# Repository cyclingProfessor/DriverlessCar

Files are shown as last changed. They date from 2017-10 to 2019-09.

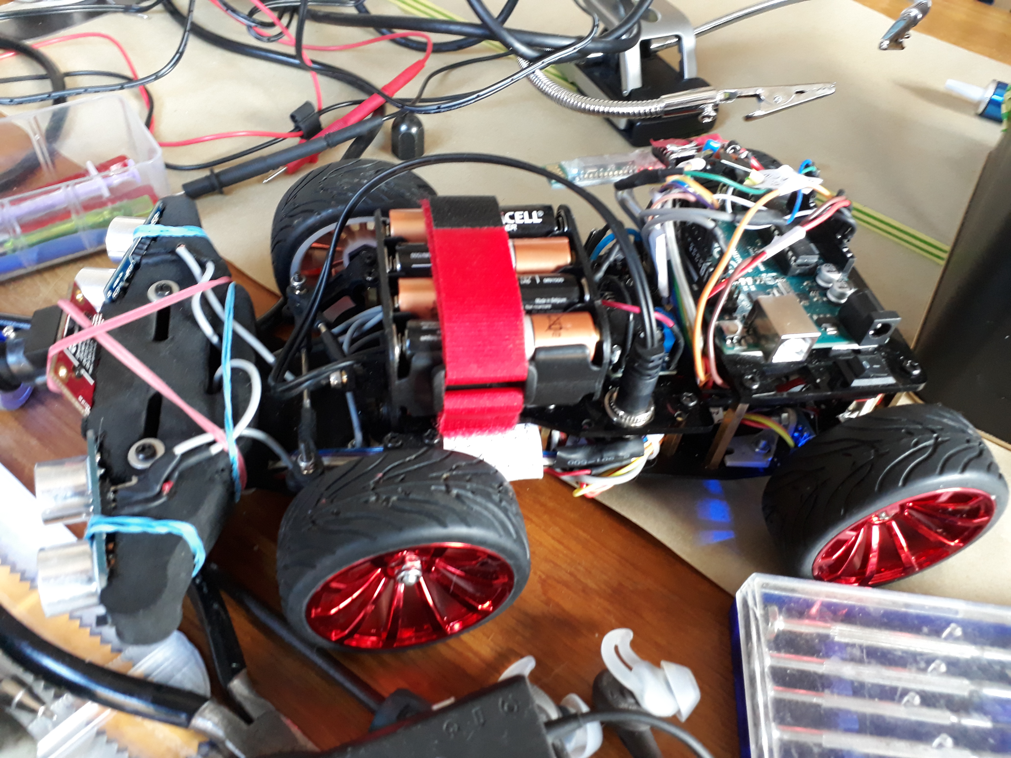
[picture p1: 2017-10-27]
Pictures/20171027_104041.jpg

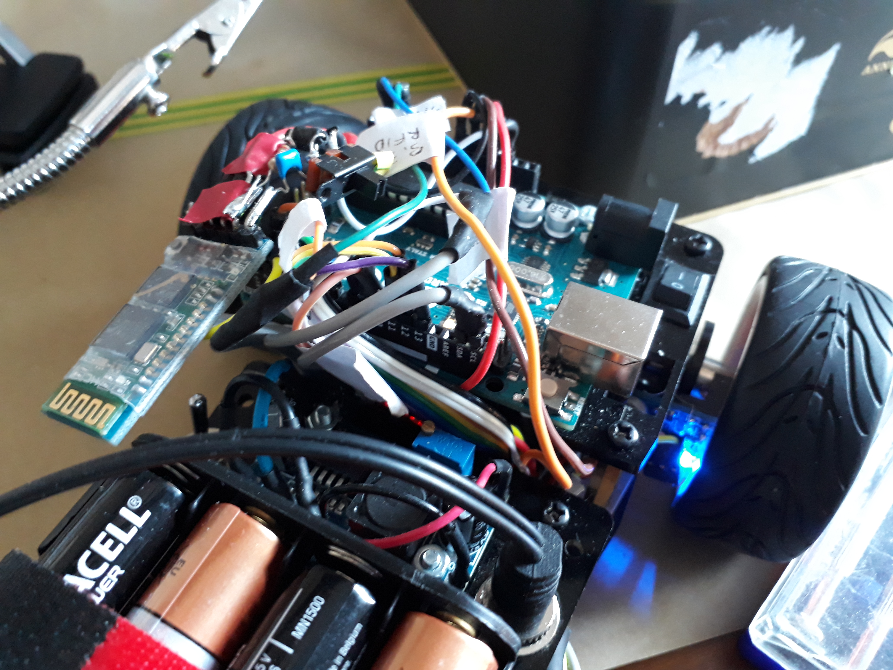
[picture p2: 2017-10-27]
Pictures/20171027_104059.jpg

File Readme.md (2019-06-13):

Complementary Infrastructure.
=============================
We live in a new age of automation, where the bins talk to the street lights and the buses converse with the traffic signals.
Sensors, tiny computers, powerful motors and effective batteries have all combined to make the impossible possible.  We expect that the autonomous car will take over from the driver and that it will not drive in the same way.  Why use vision alone when all other traffic is intelligent, and the roads, and the whole place, is intelligent?
This model has five computers: an Arduino, an RFID reader, a complex 3 axis multiple sensor and a mobile phone.  It has four power supplies.  It has 14 sensors.  It can run for three hours on one set of AA batteries.  It follows a magnetic stripe, watches for pedestrians, and responds to RFID tags.  It carefully monitors its own speed and position.  Using all these myriad signals it efficiently gets from place to place.
It is a miracle that demonstrates the integrated and complementary infrastructure.

====================================================

Now moved some common code into the CarLib library - so after cloning the git archive you will need to copy this into your arduino IDE library folder.

===================

Build System.
1. Must increase the Rx gain on the ANtenna to make RFID cards read fast enough.  This means adding one line to MFSC522 before PICC_..
2. Must change cpp flags to enable C++ 2011 standard to use SPI I2C library for MMU.
3. Must change SPI to SPI1 in the SDCard library so that it looks for the SDCard on the secondary SPI bus.

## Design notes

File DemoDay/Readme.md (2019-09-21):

Demo Day Software.
==================
Camera: SettableColors.py, State.py, CompressUtil.py
These are in the Camera/openMV folder
 State does all communications management
 CompressUtil uncompresses received images
 SettableColors can read images, switch between line following and calibration, and can process calibration messages.  It also sends periodic status updates.

Bluno: DemoDay.ino
  Initialises SD card, NFC reader, distances sensors, camera and Wemos.
  Does not yet use MMU.

Wemos D1 Lite:
  Processes speed and position from quad encoders on motor.
  Listens on either WiFi or Serial to commands: turn, speed, stop etc.,
  Stop from an obstruction knows whether the object is behind or in front so that it only stops when it is travelling towards the object.
  One command gets a status report.

===================

Build System.
1. Must increase the Rx gain on the ANtenna to make RFID cards read fast enough.  This means adding one line to MFSC522 before PICC_..
2. Must change cpp flags to enable C++ 2011 standard to use SPI I2C library for MMU.
3. Must change SPI to SPI1 in the SDCard library so that it looks for the SDCard on the secondary SPI bus.

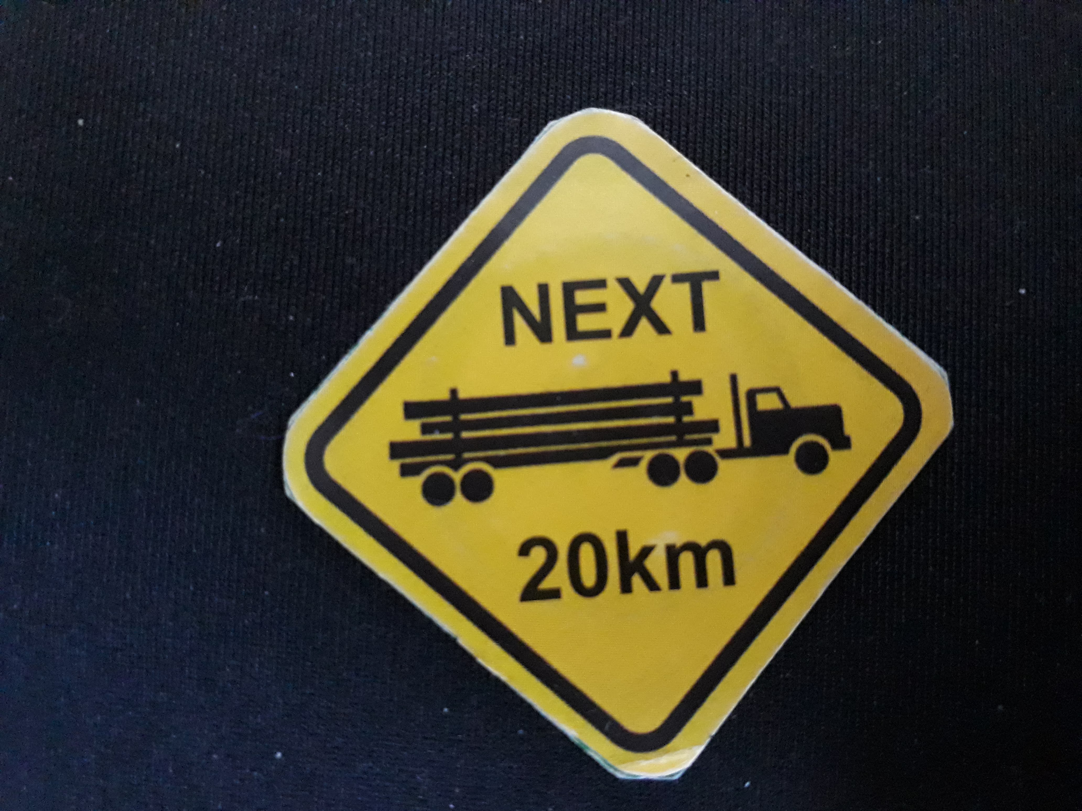
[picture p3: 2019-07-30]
Pictures/04EC8AFA904980.jpg

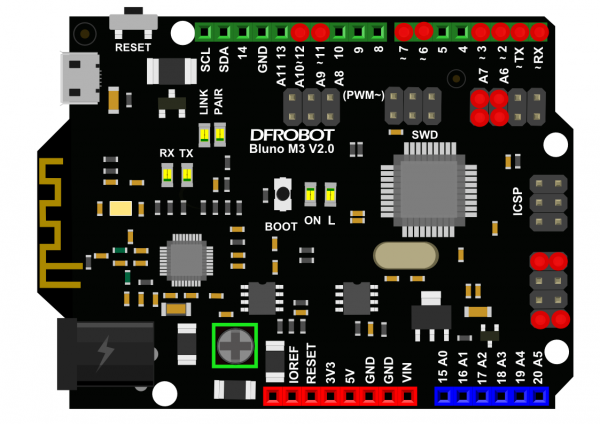
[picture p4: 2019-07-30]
Bluno M3/600px-PWM.png

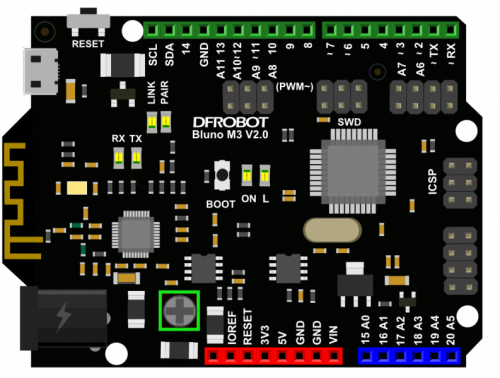
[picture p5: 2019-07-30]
Bluno M3/500px-Bluno_M3_Interrupt.png

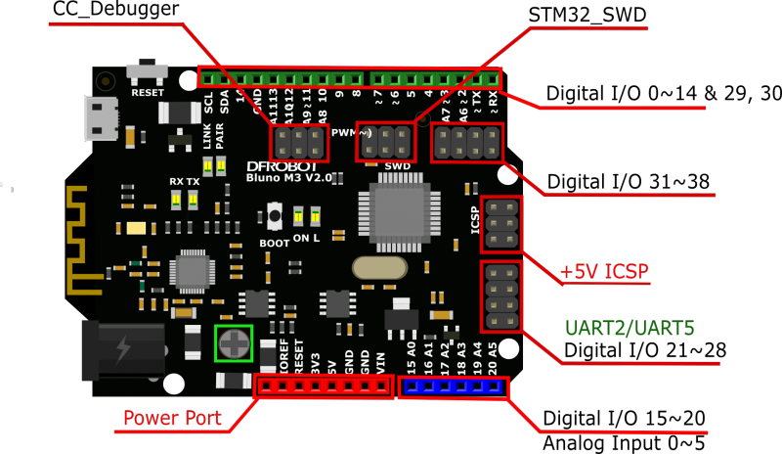
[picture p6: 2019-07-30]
Bluno M3/800px-DFR0329_M3GPIO.png

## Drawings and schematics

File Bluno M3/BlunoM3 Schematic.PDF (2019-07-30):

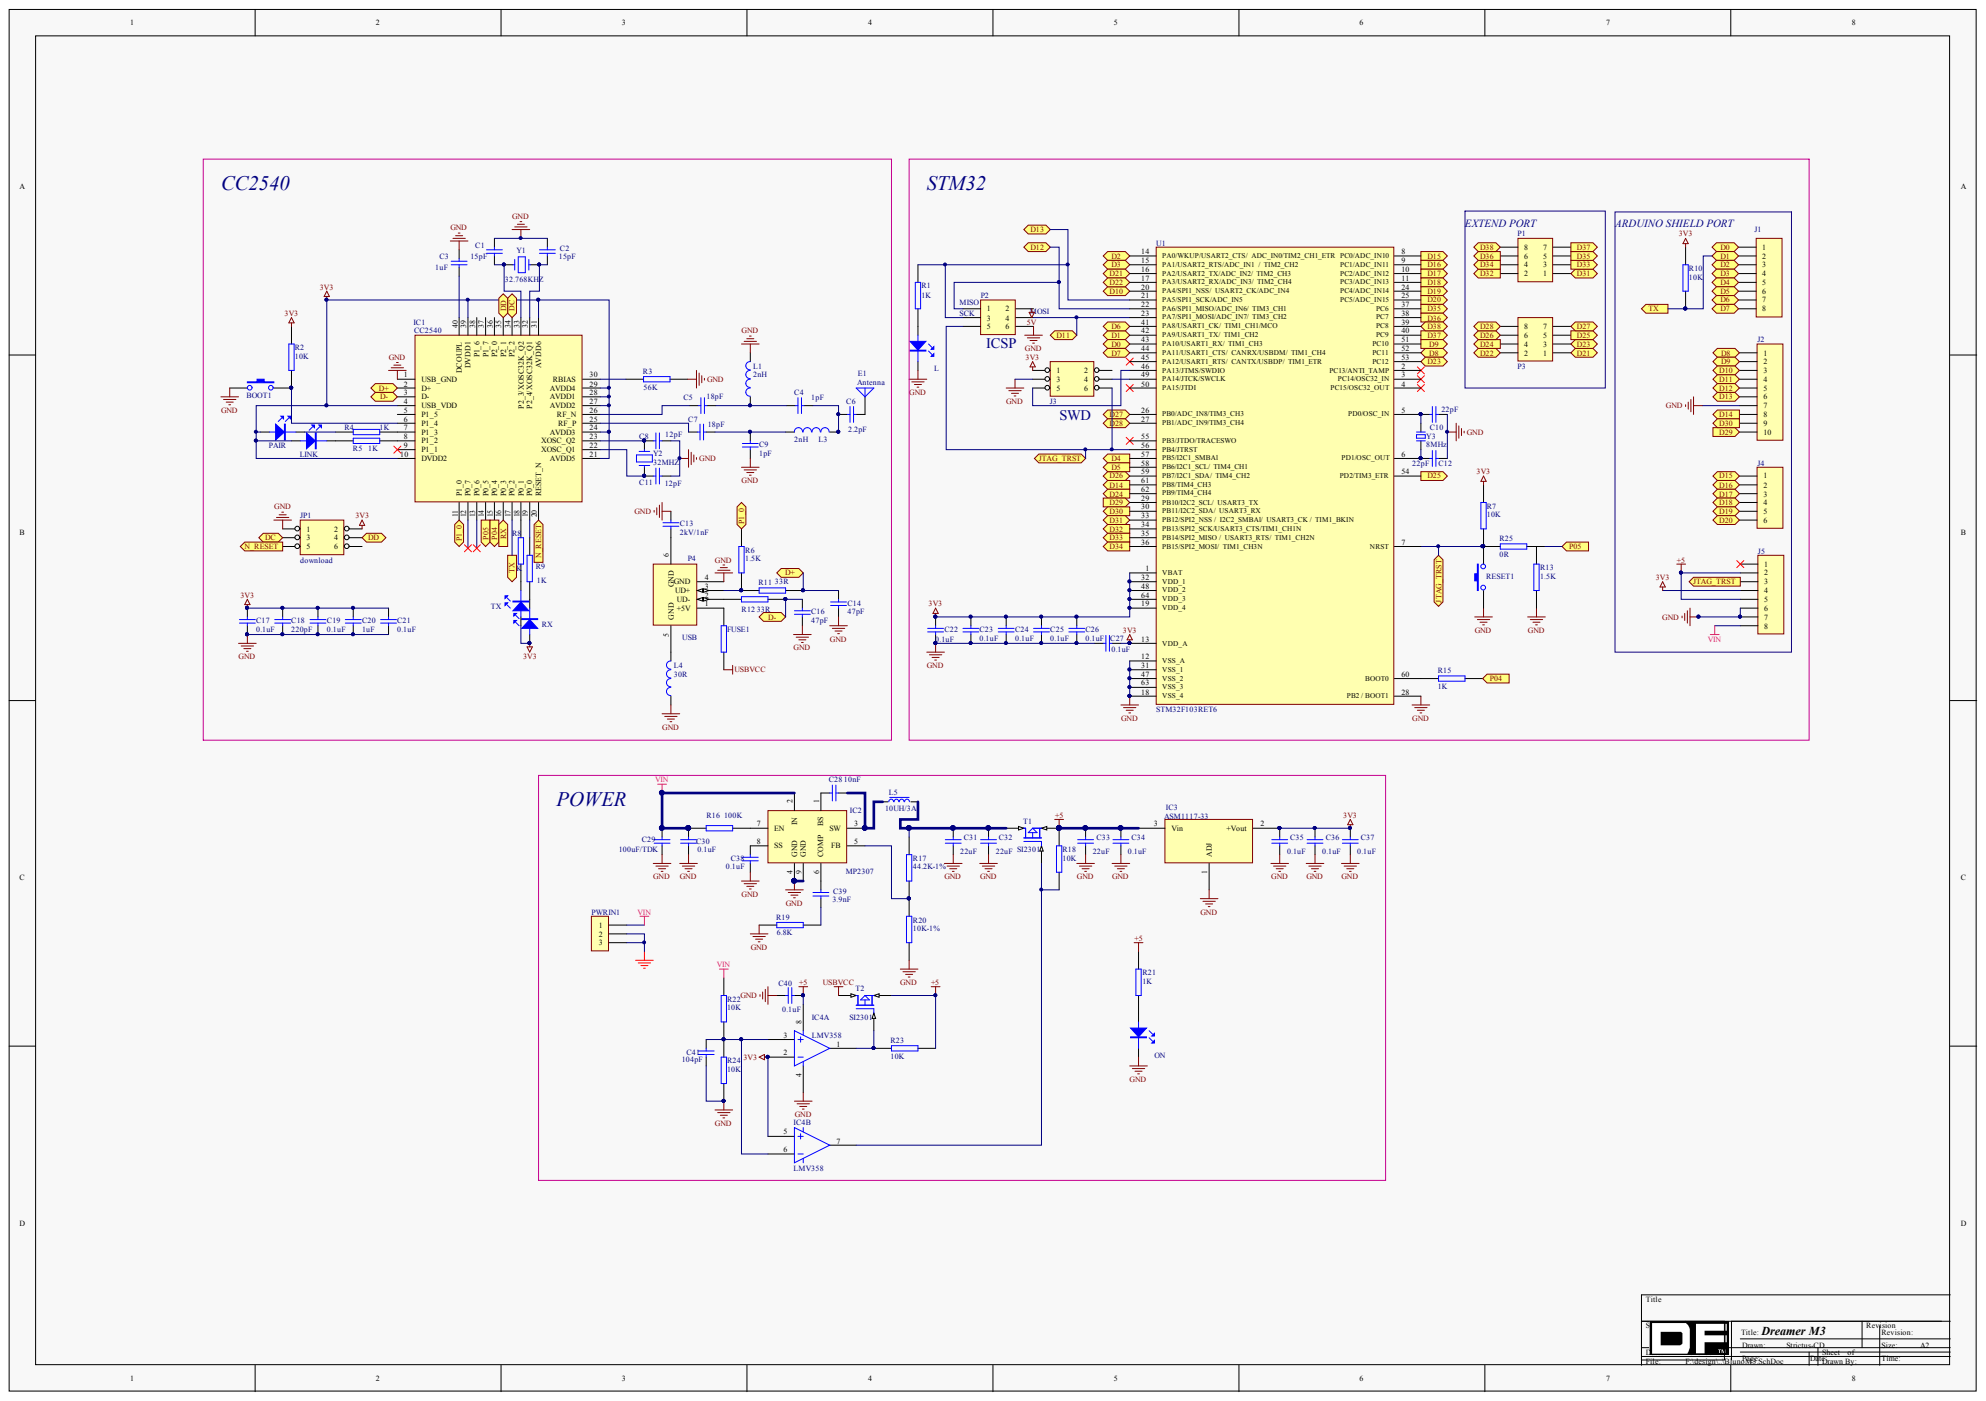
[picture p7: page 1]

3 4 5 6 | | PA14/JTCK/SWCLK 49

PB0/ADC_IN8/TIM3_CH3 26 | 3V3

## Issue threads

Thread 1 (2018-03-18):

No need to remove any I2C bytes from the buffer.

Koepel, 2018-03-18:
In the file "DriverlessCar/camera/Arduino/ReadAsMaster/ReadAsMaster.ino", the garbage bytes are tossed away when the amount of requested bytes was not received. That is not needed.

The Wire library uses packets of data (although it uses the Arduino Stream class).

Koepel, 2018-06-06:
Did something change ? I can not find it anymore. I think you used the word "garbage" in that file. Was it in another file, or is there a mix-up of Wire.avaible() and Serial.available() ? I was only talking about the I2C bus and the Wire library.

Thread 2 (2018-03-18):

Store the millis() value as a unsigned long, always use subtraction.

Koepel, 2018-03-18:
To avoid the rollover problem, the millis() value should be stored as a unsigned long and only a subtraction should be used to calculate the passed time. That subtraction must be done with two unsigned long variables.

See the Blink Without Delay example.

I spotted those problems in the next files. Sometimes the millis() value is stored in a long and sometimes the subtraction is missing. Comparing a value directly with millis() will go wrong with a rollover after about 50 days.

- "DriverlessCar/Sonar/Sonar.ino"
- "DriverlessCar/Polulo/reader/reader.ino"
- "DriverlessCar/lineFollow/Sensor.cpp"
- "DriverlessCar/lineFollow/Actions.cpp"
- "DriverlessCar/lineFollow/lineFollow.ino"
- "DriverlessCar/GyroMagnetAccel/GyroMagnetAccel.ino"

cyclingProfessor, 2018-06-06:
Thanks for this - however a battery driven toy is unlikely to last 50+ days :-)
Much of the logic for millis() has now changed.

Closed 2018-06-06.

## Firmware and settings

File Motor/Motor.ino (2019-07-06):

#include "Encoder.h"
#include "Ticker.h"
#include <ESP8266WiFi.h>
#include "Servo.h"

const char *Version = "Motor/Servo Controller V1.1"; 
const char *ssid = "ESPcarAP";
const char *password = "thisisnotaspoon";
int usingWiFi = false;

/***********************************************************************************************************\
* See https://docs.google.com/spreadsheets/d/1bhfsjG0d4l3q6j9Bx6Ja7MYPekk8pvvGrTb8yf0j5cc/edit?usp=sharing
* for details on ESP8266 pinout and its relationship to D1 Mini
\***********************************************************************************************************/

//WiFi Controls:
//
// + -Motor more forwards
// - -Motor more backwards
// 0 -Motor stop
// s - print stats
// L - Turn servo to Left
// R - Turn Servo to Right
// C - Centre servo
//
// Since this is run by the Wemos D1 Lite it can read from either Serial or from the Wifi

// UART protocol also has 'W' to toggle WiFi, '|n' and '~n' for direct speed and turn control.
char SPEED_CONTROL = '|';
char TURN_CONTROL = '~';

enum Command {
  NONE, HELP, WIFI, REPORT, TURN_LEFT, TURN_RIGHT, TURN_STRAIGHT, MOTOR_PLUS, MOTOR_MINUS, MOTOR_STOP, SET_SPEED, SET_TURN, BLOCK_BACK, BLOCK_FRONT
};

// Change to using Pololo TB6612FNG Mosfet controller

Command translate[128];
int commandArgument = 10;
/////////////////////////////////////// Pin Assignments /////////////////////////
int dir1Pin = D3; // => to TB6612FNG Pin INA1
int dir2Pin = D4; // => to TB6612FNG Pin INA2
int speedPin = D5; // => to TB6612FNG Pin PWMA (Needs to be a PWM pin to be able to control motor speed)
int steerPin = D6; // => Servo Control Wire (Orange) (Needs to be a PWM pin to be able to control servo angle)
int servoMotorPower = D8; // => Mosfet Board Signal, TB6612FNG STDY (Needs to start LOW (which is very rare on ESP8266))
int quadPinYellow = D1; // Needs Interupt
int quadPinGreen = D2; // Needs Interupt

///////////////////////////// Tunable constants /////////////////////////////////
#define SPEED_STEP 10
int desiredSpeed = 0;

const int NEUTRAL_ANGLE = 90;
int angle = NEUTRAL_ANGLE;

/////////////////// Hardware considerations ////////////////////////////
const int MAX_SERVO = 2000;
const int MIN_SERVO = 1000;
const int GLITCH = 40;  // How much to overturn to compensate for hysteresis
const int DELAY= 45; // How long to wait for a turn to complete.
unsigned long waitTime;
bool turnBack = false;

////////////////////// Speed and position calculations //////////////////
volatile int spCalcOfffset = 0;
volatile int speedEstimate[4]; // Average over 4 readings.
volatile int currentSpeed = 0;
volatile int lastPosition = 0;
volatile unsigned long lastTime = 0L;
int diffP = 0;
int diffT = 0;

//////////////////////////////// Objects ////////////////////////////
Encoder enc(quadPinYellow,quadPinGreen);
Ticker speedSetter;
WiFiServer server(3000);
WiFiClient client;
Servo   servo;

///////////////////////////////// CODE //////////////////////////////////////////
void setup() {  // Setup runs once per reset
  delay(1000);  // Wait for pins to settle.
  Serial.begin(115200);
  Serial.println(Version);
  pinMode(steerPin, OUTPUT);
  servo.attach(steerPin, MIN_SERVO, MAX_SERVO);
  servo.write(angle);
  delay(10);  // Wait for servo ctrl pin to settle.
  
  pinMode(servoMotorPower, OUTPUT);
  digitalWrite(servoMotorPower, HIGH);

  //Define TB6612FNG Dual H-Bridge Motor Controller Pins
  pinMode(dir1Pin, OUTPUT);  
  pinMode(dir2Pin, OUTPUT);
  pinMode(speedPin, OUTPUT);
  analogWrite(speedPin, 0);//Sets speed variable via PWM
  digitalWrite(dir1Pin, HIGH);
  digitalWrite(dir2Pin, HIGH);      
  
  speedSetter.attach_ms(10, setSpeed);
  for (int command = 0 ; command < 128 ; command++) {
    translate[command] = NONE;
  }
  translate['H'] = translate['?'] = HELP;
  translate['+'] = MOTOR_PLUS;
  translate['-'] = MOTOR_MINUS;
  translate['0'] = MOTOR_STOP;
  translate['s'] = REPORT;
  translate['L'] = TURN_LEFT;
  translate['R'] = TURN_RIGHT;
  translate['C'] = TURN_STRAIGHT;
}

void setSpeed() {
  static int counter = 0;
  static int motorPower = 0;
  static const int startPower = 300;
  
  unsigned long time = micros(); // Remember to check for overflow.
  int position = enc.read();
  if (time > lastTime) {
    // update speed estimate
    diffP = lastPosition - position;
    diffT = time - lastTime;
    // Circular buffer the speed estimate.
    
    // spCalcOfffset points to last entered speed - so remove this from total.
    currentSpeed -= speedEstimate[spCalcOfffset];
    
    // Put in new guess
    speedEstimate[spCalcOfffset] = (10000L * diffP) / diffT;
    currentSpeed += speedEstimate[spCalcOfffset];
    
    spCalcOfffset = (spCalcOfffset + 1) & 3;
  }
  lastTime = time;
  lastPosition = position;

  // Now set speed itself! Only every ten clicks
  counter ++;
  if (counter > 9) {
    counter = 0;
    if (desiredSpeed == 0) { // Stop is easy.
      analogWrite(speedPin, 0);//Sets speed variable via PWM
      digitalWrite(dir1Pin, HIGH);
      digitalWrite(dir2Pin, HIGH);
      return;      
    }
    if (currentSpeed > -5 && currentSpeed < 5) { // Overcome stopped friction.
        motorPower = startPower;
    }

    boolean forwards = (desiredSpeed >= 0);
    if (currentSpeed < desiredSpeed - 10) {
        motorPower += forwards ? 10 : -10 ;
    }
    if (currentSpeed > desiredSpeed + 10) {
        motorPower += forwards ? -10 : 10 ;
    }
    analogWrite(speedPin, motorPower);//Sets speed variable via PWM
    digitalWrite(dir1Pin, forwards ? HIGH : LOW);
    digitalWrite(dir2Pin, forwards ? LOW : HIGH);
  }
}

void toggleWiFi() {
  usingWiFi = ! usingWiFi;
  if (usingWiFi) {
    WiFi.softAP(ssid, password);
//      IPAddress myIP = WiFi.softAPIP();
    server.begin();
  } else {
    if (client) {
      client.stop();
    }
    server.stop();
    WiFi.softAPdisconnect(true); 
  }
}

Command getCommand() {
  if (usingWiFi) { // Is the WiFi server running?
    if (!client || !client.connected()) { // Does it NOT a current client?
      client = server.available(); // Get a WifFi client.
    }
    if (client) { // Do we have a current WiFi client?
      if (client.connected()) {
        if (client.available() > 0) {
          return(translate[client.read()]); // Return point here for reading a WiFi
        }
      } else { // Client has died - kill our WiFiClient object.
        client.stop();
      }
    }
  }

  // Here we have not managed to read from Wifi: try Serial protocol
  if (Serial.available()) {
    int next = Serial.read();
    if (translate[next] != NONE) {
      return translate[next];
    }
    // Protocol bytes are always not control bytes so cannot be misunderstood.  
    // They are '|' for speed and '~' for Turn, followed by an argument byte
    // Speed : take of ten from byte value, and multiply by ten.
    if (next == 'W') {
      return WIFI;
    }
    if (next == 'F') {
      return BLOCK_FRONT;
    }
    if (next == 'B') {
      return BLOCK_BACK;
    }
    // There will be another character - just wait here now.
    while (!Serial.available()) {
    }
    if (next == SPEED_CONTROL) {
      commandArgument = (Serial.read() - 10) * 10;
      return SET_SPEED;
    }
    if (next == TURN_CONTROL) {
      commandArgument = 10 * Serial.read();
      return SET_TURN;
    }
  }
  return NONE;  // Do nothing!
}

void report(Stream &out) {
  out.print("EstimatedSPeed: ");
  out.println(currentSpeed);
  out.print("Desired Speed: ");
  out.println(desiredSpeed);
  out.print("Turn Angle: ");
  out.println(angle); 
  out.print("WiFi: ");
  out.println(usingWiFi ? "ON" : "OFF");
  out.flush();
}

void help(Stream & out) {
  out.print(Version);
  out.print(HELP);
  out.flush();
}


void loop() {
  int turnTo;
  if (turnBack) {
    if (millis() > waitTime + DELAY) {
      turnBack = false;
      servo.write(angle);
    }
  }

  switch (getCommand()) {
    case WIFI: // Only UART - Toggle Wifi
      toggleWiFi();
      break;
    case HELP: // 'H' or '?'
      if (usingWiFi) help(client);
       help(Serial);
      break;
    case MOTOR_PLUS: // Only from Wifi - Motor 1 Forward
      desiredSpeed = min(desiredSpeed + SPEED_STEP, 90);
      break;
    case MOTOR_MINUS: // Only Wifi - Motor 1 Stop (Brake)
      desiredSpeed = max(desiredSpeed - SPEED_STEP, -60);
      break;
    case MOTOR_STOP: 
      desiredSpeed = 0;
      break;        
    case TURN_LEFT:
      // always arrive from the same direction (from a higher angle)
      angle -= 10;;
      servo.write(angle);
      break;
    case TURN_RIGHT:
      // always arrive from the same direction (from a higher angle)
      angle += 10;
      servo.write(angle+GLITCH);
      waitTime = millis();
      turnBack = true;
      break;
    case TURN_STRAIGHT:
      angle = NEUTRAL_ANGLE;
      servo.write(angle+GLITCH);
      waitTime = millis();
      turnBack = true;
      break;
    case REPORT:
      if (usingWiFi) report(client);
        report(Serial);
      break;
    case BLOCK_FRONT:
      // Blockage in front
      desiredSpeed = min(desiredSpeed, 0);
      break;
    case BLOCK_BACK:
      // Blockage behind
      desiredSpeed = max(desiredSpeed, 0);
      break;
    case SET_SPEED:
      desiredSpeed = max(min(commandArgument, 90), -60);
      break;
    case SET_TURN:
      turnTo = commandArgument;
      if (turnTo > angle) { // Turn Right
        // always arrive from the same direction (from a higher angle)
        turnTo += GLITCH;
        waitTime = millis();
        turnBack = true;
      } 
      servo.write(turnTo);
      angle = commandArgument;
      break;
    default:
      break;
  }
}

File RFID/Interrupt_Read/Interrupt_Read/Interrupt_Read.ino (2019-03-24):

#include <timerobj.h>
#include <SPI.h>
#include <MFRC522.h>

#define RST_PIN         9
#define SS_PIN          10
#define IRQ_PIN         8

HardwareSerial &Serial = Serial1;

MFRC522 mfrc522(SS_PIN, RST_PIN);
#define BLOCKS 16
byte buffer[2 * BLOCKS + 2];
#define VAL_OFFSET 6

volatile boolean bNewInt = false;
volatile boolean foundCard = false;
unsigned char regVal;

void readCard();
//Timer triggerTimer(50, readCard, t_period, NULL );

void setup() {
  Serial1.begin(115200); // Initialize serial communications with the PC
  while (!Serial1);    // Do nothing if no serial port is opened (added for Arduinos based on ATMEGA32U4)
  SPI.begin();        // Init SPI bus

  mfrc522.PCD_Init();

  /* setup the IRQ pin*/
  pinMode(IRQ_PIN, INPUT_PULLUP);

  /*
      Allow the ... irq to be propagated to the IRQ pin
      For test purposes propagate the IdleIrq and loAlert
  */
  mfrc522.PCD_WriteRegister(mfrc522.ComIEnReg, 0x20);
  mfrc522.PCD_WriteRegister(mfrc522.DivIEnReg, 0x90);

  /*Activate the interrupt*/
  attachInterrupt(IRQ_PIN, readCard, RISING);
  activateRec(mfrc522);
  delay(100);
  Serial1.println("End setup");
}

/**
   Main loop.
*/
void loop() {

  //readCard();
  if (bNewInt) { //new read interrupt
    bNewInt = false;
    Serial.print("Interrupt.");
    if (foundCard) {
      dump_byte_array(mfrc522.uid.uidByte, mfrc522.uid.size);
      Serial.print("<");
      Serial.print((char *)buffer + VAL_OFFSET);
      Serial.print(">");
    }
    Serial.println();
    foundCard = false;
  }

  Serial.println("Beginning to Wait for a Card.");
  delay(4000);
} //loop()

/**
   Helper routine to dump a byte array as hex values to Serial.
*/
void dump_byte_array(byte *buffer, byte bufferSize) {
  for (byte i = 0; i < bufferSize; i++) {
    Serial1.print(buffer[i] < 0x10 ? " 0" : " ");
    Serial1.print(buffer[i], HEX);
  }
}
/**
   MFRC522 interrupt serving routine
*/
void readCard() {
  bNewInt = true;
  clearInt(mfrc522);
  // Look for new cards
  if ( ! mfrc522.PICC_IsNewCardPresent())
    return;
  mfrc522.PICC_ReadCardSerial(); //read the tag data
  if (!readCardData())
    return;
  activateRec(mfrc522);
  foundCard = true;
}

/*
   The function sending to the MFRC522 the needed commands to activate the reception
*/
inline void activateRec(MFRC522 mfrc522) {
  mfrc522.PCD_WriteRegister(mfrc522.FIFODataReg, mfrc522.PICC_CMD_REQA);
  mfrc522.PCD_WriteRegister(mfrc522.CommandReg, mfrc522.PCD_Transceive);
  mfrc522.PCD_WriteRegister(mfrc522.BitFramingReg, 0x87);
}

/*
   The function to clear the pending interrupt bits after interrupt serving routine
*/
inline void clearInt(MFRC522 mfrc522) {
  mfrc522.PCD_WriteRegister(mfrc522.ComIrqReg, 0x7F);
}

boolean readCardData() {
  MFRC522::StatusCode status;
  byte size = BLOCKS + 2;

  byte blockAddr = 6;
  status = (MFRC522::StatusCode) mfrc522.MIFARE_Read(blockAddr, buffer, &size);
  if (status != MFRC522::STATUS_OK) {
    return false;
  }
  blockAddr = 10;
  status = (MFRC522::StatusCode) mfrc522.MIFARE_Read(blockAddr, buffer + 16, &size);
  if (status != MFRC522::STATUS_OK) {
    return false;
  }
  
  // second byte indicates length
  int length = buffer[1] - 3;  // Need to subtract 3 to get actual string length
  buffer[length + VAL_OFFSET] = 0;
  return true;
}

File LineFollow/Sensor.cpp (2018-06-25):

#include "LineFollow.h"

//////////////////////////////////////////////////////////////////////////////////////
CameraSensor::CameraSensor(int pin): controlPin(pin) {
    watching = false;
    pinMode(controlPin, OUTPUT);
    CameraSensor::calibrate();
}

void CameraSensor::watch() {
    digitalWrite(controlPin, HIGH);
    watching = true;
}
void CameraSensor::calibrate() {
  digitalWrite(controlPin, LOW);
  watching = false;
}

bool CameraSensor::isWatching() {
	return watching;
}

// This must not be called unless the camera is started
unsigned CameraSensor::getNormalisedValue() {
	if (!watching) {
		return 0; // This should never happen
	}
  byte value = MID_POINT;
  Wire.requestFrom(CAMERA_ADDR, 1);
  if (Wire.available()) {
    value = Wire.read();
  }
  return (value <= MAX_MESSAGE) ? value : MID_POINT ;
}

//////////////////////////////////////////////////////////////////////////////////////
void MagSensor::start() {
  while (!mag.init());
  mag.enableDefault();
  mag.writeReg(LIS3MDL::CTRL_REG2, 0x60);
}

unsigned MagSensor::getNormalisedValue() {
  return (abs(mag.m.x) + abs(mag.m.y) + abs(mag.m.z)) / 100u;
}

void MagSensor::update() {
    mag.read();
}

MFRC522 mfrc522(RFID_SS_PIN, RFID_RST_PIN);  // Create RFID reader instance

//////////////////////////////////////////////////////////////////////////////////////
void RFID::start() {
  SPI.begin();      // Init SPI bus
  mfrc522.PCD_Init();   // Init MFRC522
}

///////////////////////////////////////////////////////////////////////////////////////
// This utility function just reads and returns the text from a noticed RFID tag.
///////////////////////////////////////////////////////////////////////////////////////
const byte *RFID::readCardData() {
  const int VAL_OFFSET = 6;
  if (!mfrc522.PICC_IsNewCardPresent() || !mfrc522.PICC_ReadCardSerial()) {
    return NULL;
  }

  MFRC522::StatusCode status;
  byte size = BLOCKS + 2;

  byte blockAddr = 6;
  status = (MFRC522::StatusCode) mfrc522.MIFARE_Read(blockAddr, buffer, &size);
  if (status != MFRC522::STATUS_OK) {
    return NULL;
  }
  blockAddr = 10;
  status = (MFRC522::StatusCode) mfrc522.MIFARE_Read(blockAddr, buffer + 16, &size);
  if (status != MFRC522::STATUS_OK) {
    return NULL;
  }

  // Avoid seeing the same card twice!
  mfrc522.PICC_HaltA();

  // second byte indicates length
  int length = buffer[1] - 3;  // Need to subtract 3 to get actual string length
  buffer[length + VAL_OFFSET] = 0;
  return buffer + VAL_OFFSET;
}

//////////////////////////// Echo locator stuff ///////////////////////////////////////////////////////
NewPing sonar[2] = {
  NewPing(TRIGGER_PIN_LEFT, ECHO_PIN_LEFT, MAX_DISTANCE),
  NewPing(TRIGGER_PIN_RIGHT, ECHO_PIN_RIGHT, MAX_DISTANCE)
};

void EchoMonitor::start(int freq) {
  pinMode(TRIGGER_PIN_LEFT, OUTPUT);
  pinMode(ECHO_PIN_LEFT, INPUT);
  pinMode(TRIGGER_PIN_RIGHT, OUTPUT);
  pinMode(ECHO_PIN_RIGHT, INPUT);
  pingSpeed = freq;
  pingTimer = millis();
  echo_distances[0] = echo_distances[1] = NO_OBJECT;
}
void EchoMonitor::update() {
  long distance;
  if (millis() >= pingTimer) {   // pingSpeed milliseconds since last ping, do another ping.
    pingTimer += pingSpeed;      // Set the next ping time.
    distance = sonar[which_echo].ping_cm(MAX_DISTANCE);
    if (distance > 0) {
      echo_distances[which_echo] = distance; 
    } else {
      echo_distances[which_echo] = NO_OBJECT; 
    }
    which_echo = 1 - which_echo;
  }
}
unsigned int EchoMonitor::pingSpeed; // Frequency at which we ping
unsigned long EchoMonitor::pingTimer; // Holds the next ping time.
int EchoMonitor::which_echo = 0;  // which sonar to ping next

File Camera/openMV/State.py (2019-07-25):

import image, sensor
from CompressUtil import decompressImageStart, Uncompressor, DataStore

START = '{' # 123
END = '}' # 125
MSG_GOOD = 1
MSG_PARTIAL = 0
MSG_BAD = -1
MSG_NONE = -2

# A message
# START: CMD: Length: Data : End
# e.g 8: 'D': 3: '1': '2' : '3' : 10

class Message:
    def __init__(self):
        self.command = None
        self.dataBuffer = [None for i in range(20)]
        self.status = MSG_NONE # -2 for None yet, -1 for error, 0 for partial, 1 for complete
        self.dataCount = 0
        self.expected = -1
        self.picture = image.Image(50,44,sensor.RGB565)
        self.decompressTable = bytearray(3000)

######################################################################################

class State:
    """
    Define an interface for encapsulating the behavior associated with a
    particular state of the Context.
    """
    message = Message() # Single class variable
    def __init__(self):
        self._name = "None"
    def handleChar(self, rdr, recvd):
        #print('Error : NO STATE')
        pass

class StateImageReader(State):
    def __init__(self):
        super().__init__()
        self.started = False;
        self._name = "Image Reader"
        self.width = 0
    def handleChar(self, rdr, recvd):
        if ord(recvd) > 100:
            self.started = False;
            print(self._name + " - got Bad:" + str(recvd))
            self.message.status = MSG_BAD
            rdr._state = myStateWaiting
            return
        # The first two bytes are big endian 6-bit Data (compressed) counts.
        if not self.started:
            self.message.expected = ord(recvd)
            self.started = True
            return

        self.message.expected = 64 * self.message.expected + ord(recvd)
        self.message.dataCount = 0
        self.started = False

        print("Expecting : " + str(self.message.expected))
        if self.message.expected > 1000: # Size of decode table
            print(self._name + " - got Bad Image Size:" + str(self.message.expected))
            self.message.status = MSG_BAD
            rdr._state = myStateWaiting
            return
        rdr._state = myReadPixels
        myReadPixels.begin()

class StateReadPixels(State):
    def __init__(self):
        super().__init__()
        self._name = "Pixel Reader"
        self._buffer = bytearray(3)
        self._uc = None
        self._ds = None
        self.__escaped = False
    def begin(self):
        self.__escaped = False
    def handleChar(self, rdr, recvd):
        if recvd in [END, START]: # Only two bad characters! premature!
            print(self._name + " - got Bad:" + str(recvd))
            self.message.status = MSG_BAD
            rdr._state = myStateWaiting
            return
        val = ord(recvd)
        if self.__escaped:
            val += 10
            self.__escaped = False
        elif recvd == '|':
            # wait until next character
            self.message.dataCount += 1
            self.__escaped = True
            return

        if self.message.dataCount < 3: # build up initial buffer
            self._buffer[self.message.dataCount] = val
            if self.message.dataCount == 2:
                self._ds = DataStore(self._buffer, streamed = True)
                self._uc = decompressImageStart(self.message.picture, self.message.decompressTable, self._ds)
        else:
            self._ds.setStoreToByte(val)
            self._uc.uncompressBytes()

        self.message.dataCount += 1
        if self.message.dataCount == self.message.expected:
            rdr._state = myStateEnd

class StateWaiting(State):
    def __init__(self):
        super().__init__()
        self._name = "Waiting"
    def handleChar(self, rdr, recvd):
        # Simply ignore no-start characters.
        if recvd != START:
            print(self._name + " - Still Waiting - got:" + str(recvd))
            return
        self.message.status = MSG_PARTIAL
        rdr._state = myStateCMD

class StateCMD(State):
    def __init__(self):
        super().__init__()
        self._name = "CMD"
    def handleChar(self, rdr, recvd):
        if not recvd in ['C', 'R', 'L', 'P']: # Possible commands
            print(self._name + " - got Bad:" + str(recvd))
            self.message.status = MSG_BAD
            rdr._state = myStateWaiting
            return
        # Check CMD validity
        self.message.status = MSG_PARTIAL
        self.message.command = recvd
        self.message.dataCount = 0
        if recvd == 'P': # Picture command
            rdr._state = myImageReader
            print(self._name + " - got a picture command")
            return
        rdr._state = myStateCount

class StateCount(State): # count is offset from 64 ('@') - So 'A' == 1
    def __init__(self):
        super().__init__()
        self._name = "Count"
    def handleChar(self, rdr, recvd):
        count = ord(recvd) - ord('@')
        if count > 20:
            print(self._name + " - got Bad:" + str(recvd))
            self.message.status = MSG_BAD
            rdr._state = myStateWaiting
            return
        # Check Count validity (Certainly < 20)
        # If expected = 0 then straight to END
        self.message.expected = count
        self.message.dataCount = 0
        if self.message.expected == 0:
            rdr._state = myStateEnd
        else:
            rdr._state = myStateData

class StateData(State):
    def __init__(self):
        super().__init__()
        self._name = "Data"
    def handleChar(self, rdr, recvd):
        if recvd < '0' or recvd > '9':
            print(self._name + " - got Bad:" + str(recvd))
            rdr._state = myStateWaiting
            self.message.status = MSG_BAD
            return
        self.message.dataBuffer[self.message.dataCount] = recvd
        self.message.dataCount += 1
        if self.message.dataCount >= self.message.expected:
            rdr._state = myStateEnd

class StateEnd(State):
    def __init__(self):
        super().__init__()
        self._name = "End"
    def handleChar(self, rdr, recvd):
        if recvd != END:
            print(self._name + " - got Bad:" + str(recvd))
            self.message.status = MSG_BAD
        else:
            self.message.status = MSG_GOOD # Got a whole good self.message.
        rdr._state = myStateWaiting
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

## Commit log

2017-06-26 The various sketches test in isolation the various sensors on the car. LineFollow is the whole system put together
2017-10-18 1. Changed the pins that the echo sensors use from A4/A5 to A2/A3 since the A4/A5 pins are hard wired to the I2C SCL and SDA pin when I2c is started. This meant that the echo sensors interfered with 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
    2. Also created files to make the OpenMV camera report a green line position.
    This code searches for green blob of sufficient size at an appropriate distnace in front of the car. It is very susceptible to light conditions even though it uses LAB colour coding.
2017-10-27 Beginning to add support for the OpenMV camera with line following and slave I2c
2018-05-22 The CarServo program allows you to specify the angle (10-105 degrees) for the servo motor to see what effect that has on teh wheels, and to test for repeatability and hysteresis.
2018-05-22 iThis is the program - with the newly added digital line 6 - that allows the arduino to switch between follow and calibrate modes. it sends regular fixed format angles to the line at 20cm when in fol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
    [AutoTrack.py]
2018-05-22 This sketch can be used to see the communication from the car camera. It can switch the car to/from calibrate mode using serial entries. it seems reliable with either the sketch or the car starting f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
2018-05-23 The readme.h file in CarServo no longer reflectd its use. The slave code for the openMV camera is redundant and incorporated in better examples.
2018-05-24 This is a change to fix a couple of bugs in this tester program. Specivically it correct the switch statement so that we can switch back to calibrate mode, changes the baud rate to a sensible value, 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
    [ReadAsMaster.ino]
2018-05-24 This is the auto line tracking program that runs on the OpenMV camera. It drops into calibration mode when the control line (A6) goes low. Otherwise it continually scans the horizon for a correctly c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
    [AutoTrack.py]
2018-05-24 Changes to support the line following using the camera. Actions.cpp set the desired value to 50 - it was 30 for magnetic line following. Controller.cpp just changes the debug message so that (when no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
    [Actions.cpp, Sensor.cpp]
2018-05-28 A big CHANGE. ==================================== Added a new Pro Mini Arduino to the car so that the line finding and speed tracking are not delayed by communicating with sensors. Now lineFollow do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
2018-05-30 Many changes to make the communication work between the Arduino Uno and the ProMini. the data structure is now optimised so that interrupt routine can be faster - it only needs a delay of 1ms between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
    Also added a simple CommsTest module for the Uno that can be used to produce nice sequences of commands for the ProMini with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
2018-05-31 Fixed the bugs and updated the message handling with the whole pipeline from camera to Mini. the camera uses 0-15 and low resolution for high speeds. This is passed directly to the Mini which convert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
    [Actions.cpp, AutoTrack.py, ProMini.ino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]
2018-05-31 Added an indicator so that we can tell when the first camera (LINE_MSG) arrives - the blue LED switches on. This helped bug find the fact that the malloc buffer of arrived messages did not start empt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
    [Arduino.cpp, ProMini.ino]
2018-06-06 Changed Sensors.cpp to fix the speed calculation. This involves setting up a few manifest constants to make the code more readable. The biggest change is that we needed to pretend, on start up, that 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
2018-06-06 Changed TUNR_SCALE so it is calculated from MIN and MAX angle rather than being a magic number Also included the new Arduino.start() in the ProMini.h so that the code compiles!
2018-06-06 Now made the TURN message pass the correct parameters since this has been tested with the CommsTest sketch. Also refactored speed and turn calculations for messages into helper functions.
    [Actions.cpp]
2018-06-06 Fixed compiler warnings: unsigned vs signed, implicit type conversions, volatile
    [Actuator.cpp, Arduino.cpp, ProMini.ino]
2018-06-07 Simplified and renamed the python scripts. Now AutoTrack is the working version that both calibrates and then follows a line. This is made of two halves which can be tested separately without the ove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
2018-06-07 This is a working version of the calibrate method. Look for edges and if you find just two at the right distance then they probably capture the line. Changed to resolution to the same setting in the 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
2018-06-07 The Pro Mini actually sets the MOVING PIN high and then low again so we check for this. Not really necessary - but then this is a test script !
2018-06-07 Corrected a spelling mistake in Controller.cpp and an incorrect comment in ProMini.ino Also fixed the type of a variable
    [ProMini.ino]
2018-06-07 The line sensor was set to 15 when the car was lost because the camera reported -1 which became a very large unsigned value. This was truncated to 15. Now we check for large values and report as "lin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
2018-06-07 Changes mostly due to the redesign of the hardware. Send the Line value (L) when reporting. Also only print information beginning with #
    [Actions.cpp]
2018-06-07 Since 7 also means stop there is a bug if we apply this as the new speed. Stopping between direction changes will not work. So made 7 the same effect as 0. Still maens that we can only go backwards a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
    [ProMini.ino]
2018-06-07 Fixed all compiler warnings and removed unused variables and constants
    [Actions.cpp, BT.cpp, Sensor.cpp]
2018-06-20 This test program has been enhanced so that full turn messages can be sent - to calibrate 3point turn
2018-06-20 Now only MID_POINT is used for speed zero to avoid the out of band tests for zero speed. Also had to make sure that currentSpeed is always updated so that we change speed whenever we need to, even if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
    [ProMini.ino]
2018-06-20 Changed BT.cpp so that if we are stopped by an obstacle then we do not save this when the users asks the car to stop. This had caused the bug that restoring after user stopped left the car in a stopp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
    [BT.cpp]
2018-06-20 Ignore .bin files as these are Arduino compiled images (fetched from an Arduino)
2018-06-20 BUG FIXES and Readability improvements -------------------------------------- RFID:process_rfid A line had accidentally been deleted. Whne a new RFID tag is found it not only changes the current stat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
    void ProMini::setStopped
    Changed the zero speed byte to uni formally use the toSpeedByte method for readability.
    ProMini::setTurn
    Set remembered last speed to zero because the Turn code in the ProMini finishes at zero speed.
    Changed the code so that is actually uses the parameters from the Android app.
    Now waits (up to 1sec) for a HIGH isMoving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
    [Actions.cpp]
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2018-06-22 Changed the camera module by adding an LCD screen (Nice!) This involves some code changes to initialise the LCD and to send the image. It also involves changing the Arduino connected pin from 6 to 9 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
2018-06-25 Motor controller does a fst stop if both controller lines are LOW (using back EMF) do that has been added.
2018-06-25 Moved common functions for converting speed and Turn to/from a 4 bit number into a library (CarLib) Also moved the registration code magic numbers function to the library. Placed all common manifest 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
2018-06-26 LineTrack and AutoTrack are now the same except that LineTrack is standalone. So, LineTrack just calibrates until done and then tracks a line AutoTrack calibrates until done whenever the Follow Pin s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
    the calibration is to find two near vertical lines about the right distance apart and to use the gap between to alter the current find_blobs threshold.
    When find_blobs reliably finds just one small blob we are done.
    Of course this means that the file Calibrate.py is redundant.
2018-09-28 These two programs now include auto-calibration The LineTrack program should remain the same as the AutoTrack program excepting the fact that it does not report over I2C.
2019-01-19 Changed to tb6612FNG pololu motor controller, which is smaller but has a max stall current of about 3A, so is less robust than the L298N. On the other hand it is MOSFET so provides (slightly) better 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
    [Motor.ino]
2019-01-19 Since the Bluno has built in ability to be programmed over BlueTooth we intend to program both the Camera module and the mini motor driver from the Bluno - no need to ever connect by USB! These two p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
2019-02-05 Now the Motor tester is set up to use the new EPS8266 (D1 Mini Lite) board whcih we will access using the serial pins.
    The sketch now correctly reports the angle from the built in quad encoder useing interupts on two pins.
    It presents itself as a Wifi access point : espCar, with password - "thisisnotaspoon"
    It then enters a read loop (192.168.4.1:3000)
    Use S(tatus) to get the status printed.
    Use R(ight) ,L(eft) and C(enter) to control truning,
    Use + (more forwards), - (more backwards) and 0 (brake) to control speed.
    Now compensates for hysteresis by overturning and returning.
    [Motor.ino]
2019-02-06 Changed pinout to use rmost reliable pins for interupts (D1/D2) and to use pin D8 for controlling MosFet and Motor controller STDBY since this pin begins LOW on boot. Also now use one pin for both mo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
2019-03-04 Added the veroboard Fritzing of the Motor and Servo Controller. Due to a mistake the Motr Controller board is upside down so there is a modified Fritzing part for this.
    [MotorServoController.fzz]
2019-03-04 Moved the "red/Green" - can we make the openMV camera reprogram itself fun thing to the right place.
2019-03-14 Updated CommsTest to reflect new architecture. Now OpenMV Camera is on UART 2 and Wemos D1 Lite on UART 5 This test just passes BLE/or usb input to the D1 and reports all serial from either periphera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
2019-03-14 Changed Motor driver to read commands either from WiFi or Serail. Defaul is that WiFi is off and it is turned on with the 'W' command
2019-03-14 Changed for Bluno (which has no Serial) to use Serial1. This is especially necessary for RFIDDumpInfo since the MPU libary has many references to Serial.
    The fix is to create a variable 'Serial' which is a reference to 'Serial1'
    [RFIDDumpInfo.ino, Sonar.ino]
2019-03-14 Moved some example programs to sensible places. Note that the SDCard libary as supplied for the Bluno can only use SPI. Modify the Sd2Card.cpp file to use SPI1 wherever it uses SPI and this just work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
2019-03-18 Chnaged to use pins 9,10 for SS and Reset. Also changed to use Serial1
    [RFIDDumpInfo.ino, ReadRFID_Data.ino]
2019-03-18 Now we can access the three US sensors using regular (timed) trigger pulses and collecting the echo in interrupt routines. Hence we now can, at any time without delay, work out the three distnaces wi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
2019-06-12 Changed the Motor class so that it increments speeds stedily rather than in pre-defined steps. Now it monitors actual speed and adjusts power accordingly. Furthermore, it uses a significant power to 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
    [Motor.ino]
2019-06-12 Now this test program ignores repeat cards, and also waits to check that the reader can buffer correctly.
    [ReadRFID_Data.ino]
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2019-06-13 Now the Bluno sends a direction command to the D1 when it receives position data fromthe camera. All set for line following. Should be able to switch this on and off with a "Line Following" Button, w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
    [CommsTest.ino, Motor.ino]
2019-06-13 Now we can reset light balance whenever we want and can toggle whether the camera reports the line position
    [SettableColors.py, State.py, testState.py]
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2019-07-06 Forgot to have the car stop when it saw an obstacle. Now fixed by interpretting these two messages from the Bluno
    [Motor.ino]
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2019-07-12 Now we read the NFC tags - but only the four byte id and we no longer use interuptes. Reliable and fast.
    [CommsTest.ino]
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2019-07-21 Moved the message (Message) object into the Reader structure inside State.py whcih is its natural home and avoids all of hte global statemenets in State.py
    [SettableColors.py]
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2019-07-21 Moved the Message object into the structures so that we no longer need global - and provided accessor methods in Reader to access important status info. Also supported the new fixed cost image proces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
    [State.py]
2019-07-21 Now the uncompressor uses fixed pre-allocated buffers and can be used in online fashion as data arrives from the Bluno. This first set of cahgnes just keeps everything as is except for the pre-alloca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
    [CompressUtil.py]
2019-07-22 Fixed the way that the DataStore finds if there is more data - now it actually counts the remaining bits - which works even if we are streaming. This uncovered an edge condition bug when processing c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
    [CompressUtil.py, testCompress.py]
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2019-07-24 Changed decode to use a fixed bytearray rather than allocating many of them Added profiling to check time usage in methods Changed add in Coder since we already knew the answer - this saved 90% of de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
    [CompressUtil.py]
2019-07-24 Changed the uncompressor to use a single bufffer to avoid bytearray creation
    [CompressUtil.py]
2019-07-25 Execution failure (forgotten import, mistyped names)
    [State.py]
2019-07-25 Protocol changed to not send width and height so that the reception image can be pre-allocated. Also fixed a bug where we did not seek past the useless header to the image bytes.
    [ShowImage.ino]
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2019-07-30 Change the format of the file to use the embedded id rather than the filename. Also fix some name clashes and print out more inforamtion on the terminal.
    [ShowImage.ino, ShowNFC.ino]
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2020-01-06 Fixed startup and reporting in several places.
    [DemoDay.ino, SettableColors-profiled.py]
